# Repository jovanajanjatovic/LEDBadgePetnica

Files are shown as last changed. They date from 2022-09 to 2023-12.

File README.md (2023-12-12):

srp:

# LED bedž sa mogućom kontrolom preko MCU (Mikrokontroler)

## Ovo je opis projekta LED bedž. Isplaniran, projektovan i realizovan u ISPetnica. 
### http://petnica.rs/

```markdown
<-------------------------------------------------------->
    Autori projekta:

        Jovana Janjatović:
            Email: jovana.janjatovic.05@gmail.com
            Github: https://github.com/jovanajanjatovic

        Mihajlo Ninkov:
            Email: mih.nin05@gmail.com
            Github: https://github.com/MihajloNin

        Kosta Jovanović:
            Email: kosta.jovanovic@gmail.com
            Github: https://github.com/KostaJovanovic
<-------------------------------------------------------->
```

## Cilj i opis projekta



Cilj projekta je kompletno dizajniranje PCB ploče sa LED diodama u obliku logoa IS Petnice, gde mikrokontroler omogućava kontrolu nad osvetljenjem pojedinačnih boja.



Izrada prve verzije projekta trajala je od 31.8.2022. do 10.9.2022 na letnjem seminaru elektronike u IS Petnica.
Dizajnirano je za okrugli PCB poluprečnika 3cm, koristeći SMD (surface-mounted device) i TH (through-hole) komponente.



Dizajnirano je sa idejom da se nosi kao bedž, ali to nije ograničenje.



## Hardver

```markdown
Korišćene komponente:
    22 LED diode:
        plave: 7 ()
        zelene: 3 ()
        žute: 5 ()
        crvene: 3 ()
        tamno plave (zamena za ljubičaste): 3;
    5 dioda;
    19 otpornika;
    5 NPN Bipolarnih tranzistora;
    3 držača za 3V Dugmaste baterije;
    1 CONN-SIL2 konektor;
    1 CONN-SIL7 konektor;
```

### Ideje i planovi:

Potrebno je napraviti kućište od klirita (mlečne plastke), na koje će sa unutrašnje strane biti zalepljeni držači za baterije, sa spoljne prekidač, a prednja strana bi koristila isključivo za difuziju svetla sa dioda.

Trenutni plan je da pošaljemo prvu stabilnu verziju ploče na izradu, kako bismo fizički mogli videti prednosti i mana našeg projekta, kako bismo ga optimizovali za širu proizvodnju.

Krajnji cilj projekta je da LED bedževi budu prodavani u petnici, do čega još uvek imamo dug put pred sobom.

### unapređenje:

Plan je da prilagodimo napajanje kako bi baterije činile manji udeo bedža.
Posle prve izrade ploče da ustanovimo prednosti i mane kako bismo imali jasnu sliku stvari koje možda moraju da budu drugačije.

<------>
<------>
<------>

en:

# LED badge optionally controlled with an MCU

## Project description

The goal of the project is the complete design of a PCB board with LEDs in the form of the ISPetnica logo, where the microcontroller enables control over the lighting of individual colors.

The development of the first version of the project lasted from August 31, 2022. until September 10, 2022 at the summer electronics seminar.
It is designed for a round PCB with a radius of 3cm, using SMD (surface-mounted device) and TH (through-hole) components

It's designed with the idea of being worn as a badge, but that's not a limitation.

```markdown

──▒▒▒▒▒▒───▄████▄
─▒─▄▒─▄▒──███▄█▀
─▒▒▒▒▒▒▒─▐████──█─█
─▒▒▒▒▒▒▒──█████▄
─▒─▒─▒─▒───▀████▀

```

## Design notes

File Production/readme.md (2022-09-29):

Ovde će se nalaziti fajlovi koji su relevantni za proizvodnju - BOM, PNP, GERBERI

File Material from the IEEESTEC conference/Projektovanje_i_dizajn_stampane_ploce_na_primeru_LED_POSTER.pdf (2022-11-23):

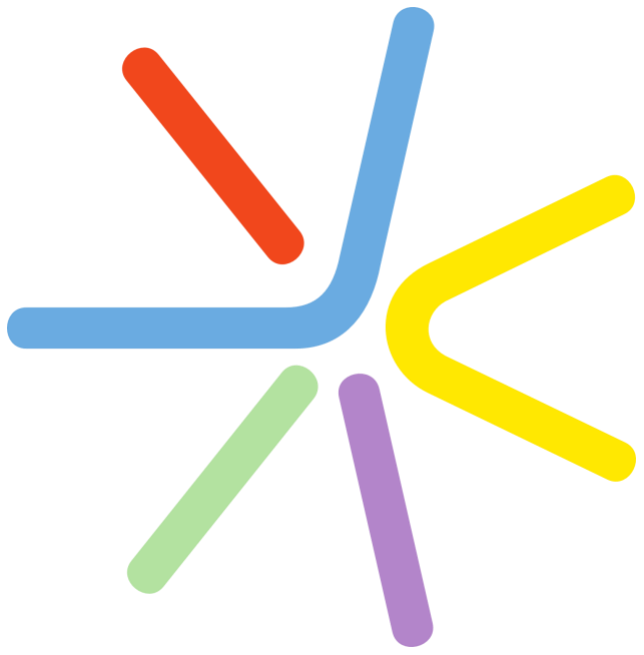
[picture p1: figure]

# Projektovanje i dizajn štampane ploče na primeru LED bedža

## Jovana Janjatović, Kosta Jovanović, Mihajlo Ninkov

- Projekat je rađen u okviru seminara elektronike u Istraživačkoj Stanici Petnica, pa je samim tim projektovana štampana ploča sa motivima logoa IS Petnica.

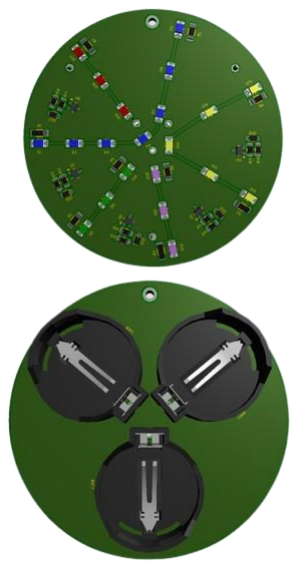
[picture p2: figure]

## Šema električnog kola

- Za ovu šemu je korišćeno:
- 22 LE SMD diode u 5 različitih boja
- SMD diode
- SMD otpornici različitih vrednosti otpornosti
- NPN bipolarnih SMD tranzistora
- Držač za dugmastu bateriju (3V)
- Konektori

## Dizajn štampane ploče

- Početna ideja je da se na jednoj strani nalaze samo LE diode, dok ostale treba da budu smeštene sa zadnje strane, međutim sve komponente na jednoj strani ploče predstavljaju kompaktniju i jeftiniju alternativu.
- Sve SMD komponente će biti lemljene od strane proizvođača ploče, dok će ostatak biti sastavljan ručno.
- Površina ploče je dizajnirana tako da vrši funkciju uzemljenja.

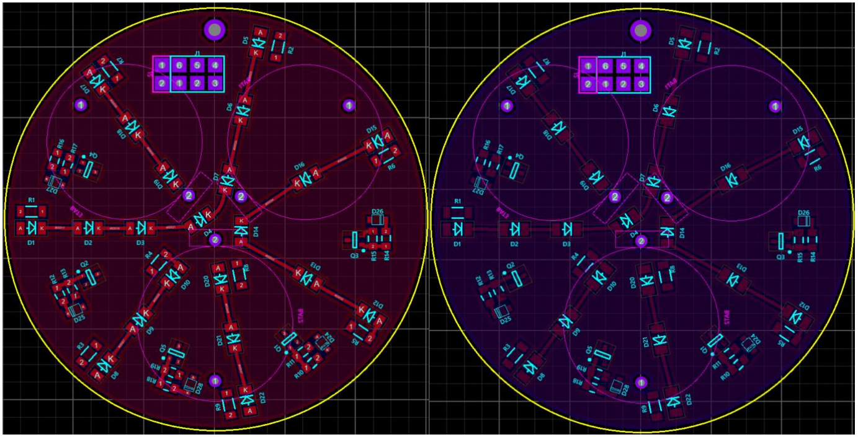
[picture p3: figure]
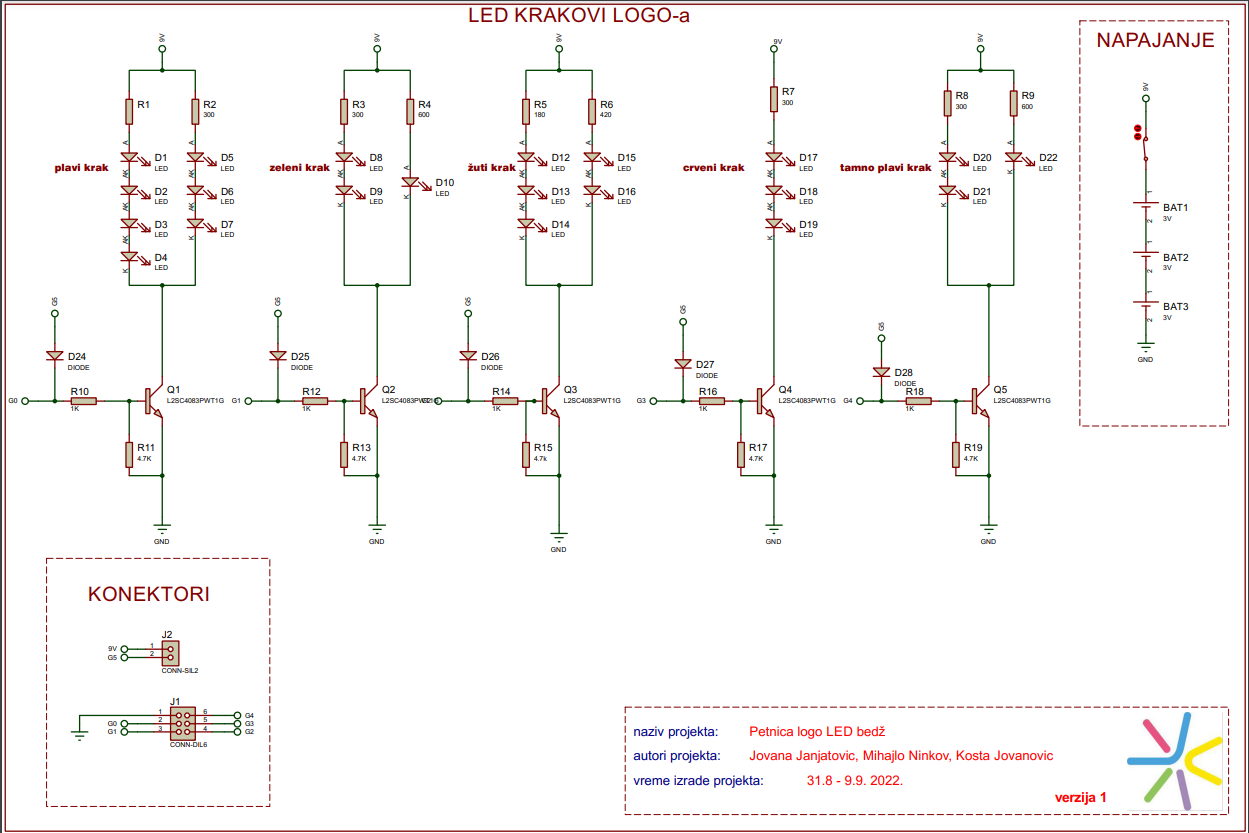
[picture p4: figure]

Jovana Janjatović
Šabačka gimnazija
Šabac
jovana.janjatovic.05@gmail.com

Mihajlo Ninkov
Gimnazija „Jovan Jovanović Zmaj“ Novi Sad
mih.nin05@gmail.com

Kosta Jovanović
V beogradska gimnazija
Beograd
kosta.jovanovic@gmail.com
- Korišćene | su | SMD
komponente | | radi
kompaktnosti sistema.
- Ovaj proces podrazumeva i izradu finalne dokumentacije - Gerber, BOM i P&P fajl

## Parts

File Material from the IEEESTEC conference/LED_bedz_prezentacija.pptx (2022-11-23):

## Projektovanje i dizajn štampane ploče na primeru LED bedža

Jovana Janjatović
Kosta Jovanović
Mihajlo Ninkov

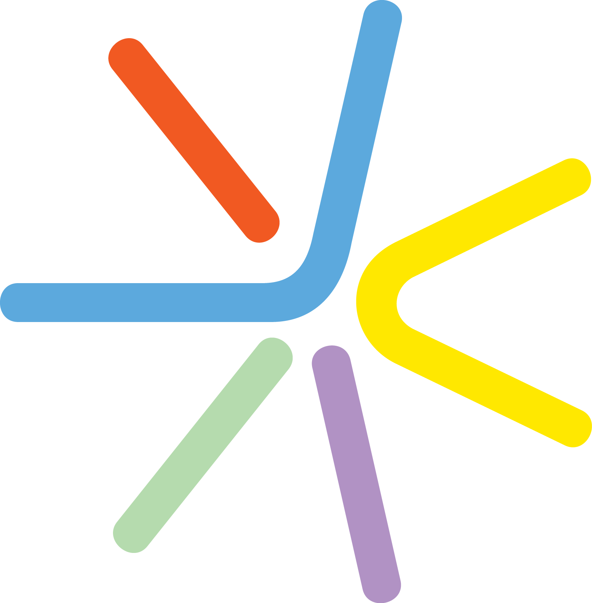
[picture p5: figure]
Seminar Astronomije - ISP -

IEEESTAC konferencija
Novembar 2022.

## IDEJA PROJEKTA

- Željene osobine našeg bedža:
  - Emitovanje svetlosti u bojama logoa IS Petnice
  - Lagana i malih dimenzija
  - Mogućnost kontrole rada diode koristeći Arduino mikrokontroler

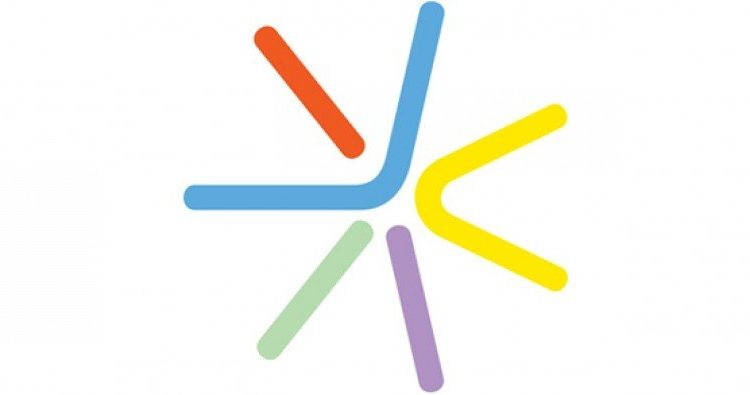
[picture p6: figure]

## OD IDEJE DO BEDŽA

1. Odabir odgovarajućih elektronskih komponenti i računanje nepoznatih vrednosti
  - 22 LED diode u 5 različiith boja;
  - diode;
  - Otpornici različitih otpornosti;
  - NPN bipolarni tranzistori;
  - Držači za 3V dugmaste baterije;
  - Konektori.

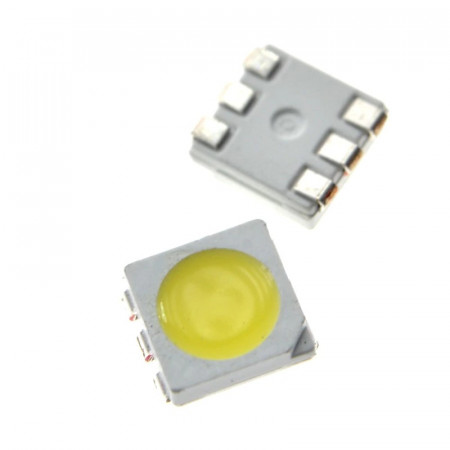
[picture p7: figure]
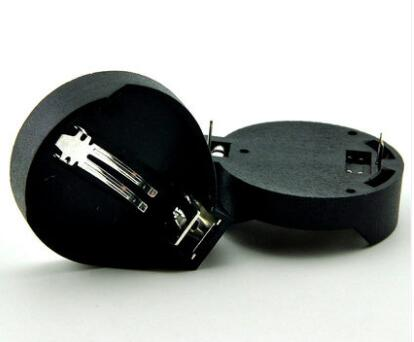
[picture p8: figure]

## OD IDEJE DO BEDŽA

2. Šematski prikaz sistema


## OD IDEJE DO BEDŽA

3. Raspoređivanje i povezivanje komponenti na PCB ploči
PCB (Printed Circuit Board) - pasivna elektronska komponenta koja omogućava ostvarivanje veze između elektronskih komponenti koja su na njoj montirane

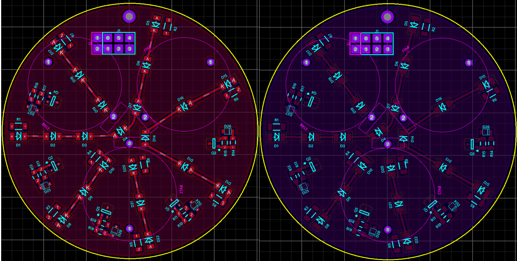
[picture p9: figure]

## OD IDEJE DO BEDŽA

4. Izrada dokumentacije neophodne za industrijsko sastavljanje PCB-a
  - BOM file
  - PnP file
  - Gerber file

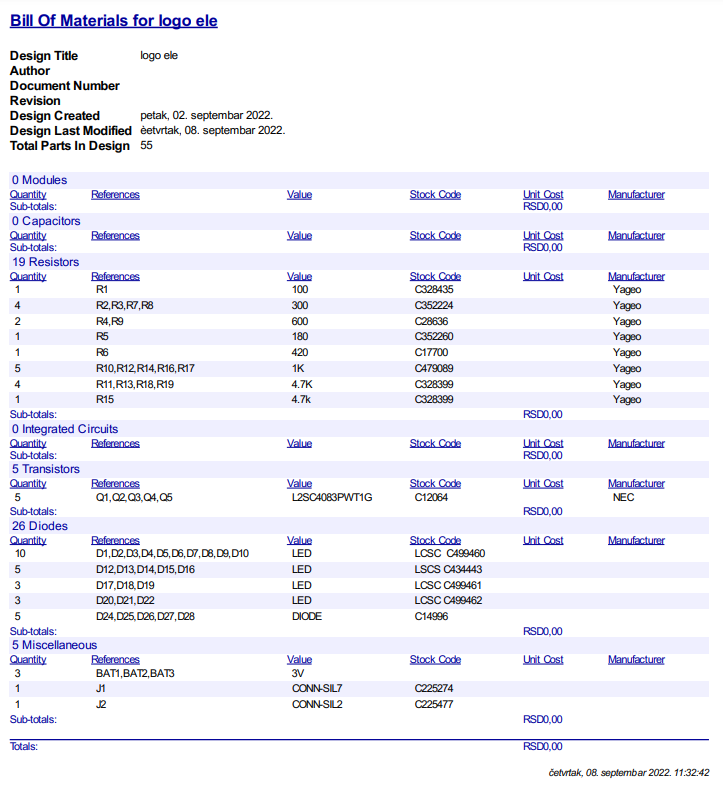
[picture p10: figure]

## PLOČA U PRVOJ ZAVRŠNOJ FAZI

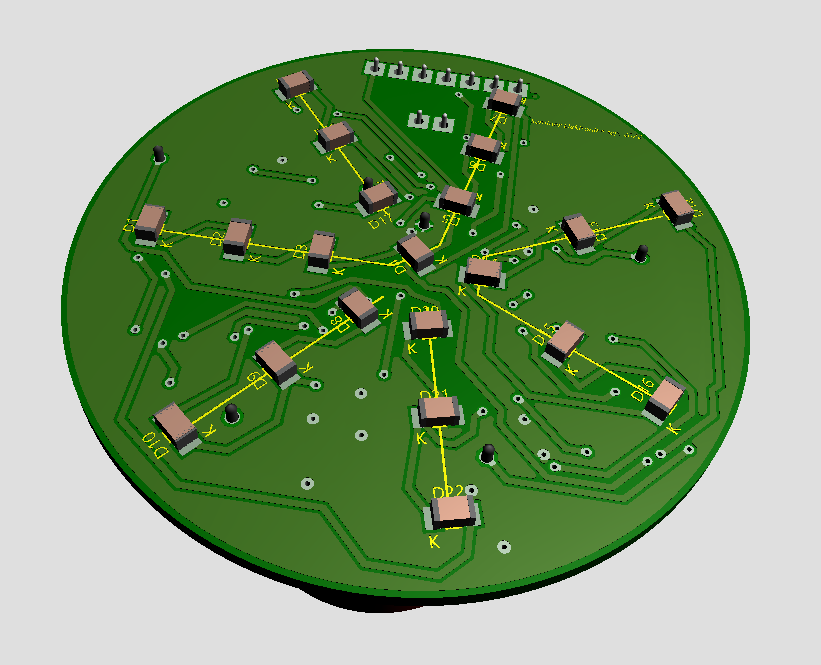
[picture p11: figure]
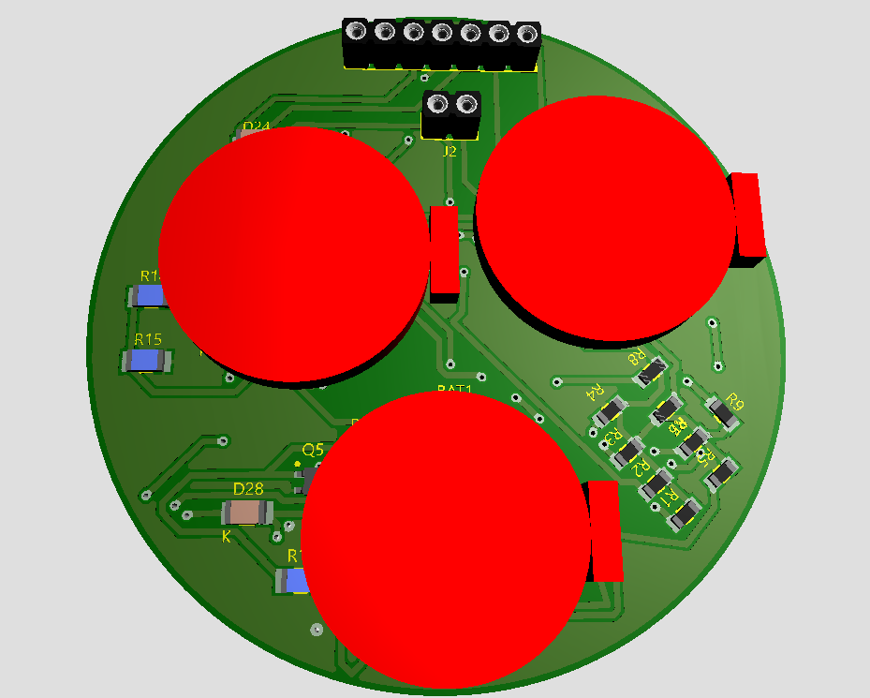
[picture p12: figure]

## Finalni izgled


## „PETNIČKI BEDŽ“ U BUDUĆNOSTI

- Razvijanje projekta:
  - Konstrukcija zaštitnog kućišta
  - Unapređivanje kvaliteta logoa
- Ideje za unapređivanje projekta:
  - Nezavisna kontrola svake diode pojedinačno
  - Optimizacija u komercijalne svrhe
  - Unapredjenje izvora napajanja
  - Dodavanje većeg broja LED dioda

## HVALA NA PAŽNJI!


Kompletan projekat


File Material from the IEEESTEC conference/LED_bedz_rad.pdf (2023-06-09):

# Projektovanje i dizajn štampane ploče na primeru LED bedža

## Jovana Janjatović, Kosta Jovanović, Mihajlo Ninkov

Sadržaj - U ovom radu se opisuje postupak izrade autentične štampane ploče (PCB) koja bi vršila funkciju svetlećeg LED bedža. Uzimajući u obzir da je ovaj rad rađen u Istraživačkoj Stanici Petnica kao seminarski projekat troje polaznika seminara elektronike, motiv ovog LED bedža je logo IS Petnica. U cilju interakcije korisnika sa štampanom pločom (bedžom), uvedena je
mogućnost | kontrolisanja | LE | dioda | pomoću | Arduino
mikrokontrolera. | U nastavku | rada, | detaljno je | opisana
metodologija izrade ovog projekta, kao i korišćene komponente, tehnike i izrada završnih dokumenata.

### I. UVOD

PCB (Printed Circuit Board), odnosno štampana ploča, predstavlja pasivnu elektronsku komponentu koja omogućava ostvarivanje veze među ostalim elektronskim komponentama. Najbitnija podela štampanih ploča je na jednoslojne i višeslojne.
Kod jednoslojnih štampanih ploča, komponente su najčešće naslagane sa jedne, a trake (provodnici) sa druge, dok se između ta dva sloja nalazi sloj izolacije. Međutim, nije nužno da jednoslojna štampana ploča sadrži provodnički element sa obe strane. Kod nekih specijalnih primena, štampana ploča sadrži provodnik samo sa jedne strane, dok se na drugoj nalazi izolatorska ploča. Višeslojne štampane ploče se koriste kod složenih elektronskih kola. Sastoje se od naizmenično raspoređenih slojeva provodnog i izolacionog materijala spojenih zajedno. Provodni slojevi su povezani preko metaliziranih otvora koji se koriste kako za montiranje, tako i za električno povezivanje komponenata.
U ovom radu opisan je postupak dizajniranja štampane ploče koristeći Proteuss 8 Professional program za dizajn štampane ploče i LCSC bazu komponenti [1]. Ovaj projekat rađen je u okviru seminara elektronike u Istraživačkoj Stanici Petnica, pa je samim tim projektovana štampana ploča sa motivima logoa IS Petnica (slika 1). Iscrtavanje šeme i dizajn štampane ploče je rađen u programu Proteus 8 Professional.

Slika 1. Logo IS Petnica.

II. ŠEMA ELEKTRIČNOG KOLA

Prvi korak u izradi projekta je bila električna šema. (Slika 2) [2,3].
Za ovu šemu je korišćeno:
- 22 LE SMD diode u 5 različitih boja [6]
- SMD diode [7]
- SMD otpornici različitih vrednosti otpornosti [5]
- NPN bipolarnih SMD tranzistora [8]
- Držač za dugmastu bateriju (3V)
- Konektori

Radi postizanja najveće moguće kompaktnosti celog sistema, korišćene su tzv. SMD komponente (Surface-Mount Device), koje se leme na površinu štampane ploče i znatno su manjih dimenzija u odnosu na komponente sa izvodima TH (Through Hole).
Prvi problem koji se pojavljuje jeste to što u bazi komponenata kompanije JLCPCB, koja bi trebalo da bude zadužena za izradu ove štampane ploče, ne postoji LE dioda koja emituje ljubičastu svetlost. Rešenje ovog problema jeste da se umesto ljubičaste koristi plava dioda koje emituju svetlost veće talasne dužine od plave koja se već korisiti za dva kraka.
Kako bi se izbeglo nošenje glomaznih baterija od 9 V i više, sa zadnje strane ploče je planirano postavljanje 3 držača dugmaste baterije od 3 V, zato što predstavljaju dosta manju i laganiju alternativu ideji početnog napajanja. Uzimajući u obzir da LE diode različitih boja zahtevaju različit radni napon, a poštujući i I Kirhofov zakon, bilo je potrebno razdeliti LE diode i ostale elektronske komponente u više grana kako bi se ideja sa postavljanjem baterije od 9 V koja napaja ceo sistem pokazala izvodljivom.
Raspodelom neophodnih komponenti u odgovarajući redosled na šematskom prikazu, pojavila se potreba za unapređenjem sistema, u vidu mogućnosti za kontrolu
svake | boje | logoa | nezavisno | koristeći | Arduino
mikrokontroler. Dodavanjem NPN bipolarnih tranzistora na svaku granu električne šeme i prespojnika koji bi vršili funkciju provodnika u slučajevima kada mikrokontroler
J. Janjatović je učenica treće godine Šabačke gimnazije,
Masarikova | 13, | 15000 | Šabac, | Srbija. | E-mail:
jovana.janjatovic.05@gmail.com
K. Jovanović je učenik četvrte godine V beogradske gimnazije, Ilije Garašanina 24, 11000 Beograd, Srbija. E-mail: kosta.jovanovic@gmail.com
M. Ninkov je učenik treće godine gimnazije „Jovan Jovanović Zmaj“, Zlatne grede 4, 21000 Novi Sad, Srbija. E-mail: mih.nin05@gmail.com nije priključen, korisnik je dobio mogućnost da po sopstvenoj želji isprojektuje šablon po kom će LE diode funkcionisati.


Slika 2. Šema električnog kola.

III. DIZAJN ŠTAMPANE PLOČE

Nakon | kompletirane | šeme | sa | svim | željenim
komponentama, neophodno je sve te komponente rasporediti u određeni raspored na štampanoj ploči. Kako bi LE diode raspodelili najpreciznije moguće, Petnički logo je prebačen u monohromatsku sliku, a zatim je sačuvan kao .bitmap dokument, iz razlog zašto je to jedini format fotografije koji Proteus dozvoljava kao uvoz. Kada su sve LE diode bile na svojim mestima, usledila je raspodela ostalih komponenti na štampanu ploču, tako da ploča zadrži kompaktan i funkcionalan izgled, odnosno da svaka komponenta ima mogućnost da se poveže u kolo, tako da ne remeti rad kako LE dioda tako i ostalih komponenti. Ideja je da se na jednoj strani nalaze samo LE diode, dok ostale treba da budu smeštene sa zadnje strane i da budu povezane viama sa prednjom stranom, da ne bi remetile rad LE dioda.
Daljim istraživanjem, uviđeno je da je znatno jeftinije i brže ukoliko sve komponente stoje na jednoj strani ploče. Iz tog razloga, ploča je dizajnirana tako da ispunjava prethodno navedene potrebe, ali i da sadrži komponente isključivo na jednoj strani.
Povezivajući komponente putevima (trace), pojavio se naredni problem, tačnije, nije moguće povezati dve komponente tako da put između njih na bilo kom svom delu skreće pod pravim uglom zato što u tom slučaju ima ulogu odašiljača signala.
Budući da će sve TH komponente biti lemljene u Srbiji, nije postojao 3D model i otisak (eng. footprint) na ploči u bazi komponenti programa u kom je projekat rađen, osim konektora, pa je bilo neophodno projektovati 3D model (u programu za 3D modelovanje – Fusion 360) i otisak na ploči (u Proteus 8 Professional) [1,9].

Jedna od stvari koje su znatno olakšale postpuak izrade jeste postavljanje površine obe strane ploče tako da vrši ulogu uzemljenja.
Finalni izgled štampane ploče prikazan je na slikama 3 i 4.


Slika 3. Prednja strana štampane ploče.


Slika 4. Zadnja strana štampane ploče.

IV. DOKUMENTACIJA

Po završetku procesa dizajna štampane ploče, neophodne je precizirati postupak izrade kompaniji kojoj se šalje ploča na izradu. U ovom slučaju, štampana ploča će biti izrađena od strane kompanije JLCPCB. Kako bi se precizno definisao postupak izrade neophodno je sastaviti tri ključna dokumenta - BOM, P&P i Gerber fajl.
Gerber
Izrada | proizvodne | dokumentacije | podrazumeva
generisanje i proveru Gerber fajlova. Ovi fajlovi sadrže podatke, kao što su koordinate za bušenje rupa sa definisanim prečnicima, referentne tačke... GERBER je standardni format za uređaje u proizvodnji štampanih ploča.

BOM
BOM fajl (Bill of Materials) predstavlja spisak svih komponenti potrebnih za proizvodnju štampane ploče. Postoje različiti tipovi BOM fajlova, ali svaki od njih mora sadržati:
- šifru proizvoda - karakteristična je za firmu koja je dizajnirala štampanu ploču
- karakteristike komponenti: na primer: otpornost, kapacitivnost...
- oznaku: na samoj štampanoj ploči, svakoj komponenti dato je ime koje je sastavljeno od slova (koje je uglavnom karakteristično za vrstu komponente, na primer: otpornik - R, kondenzator - C...) i broja (koji označava koja je po redu to komponenta određene vrste) Izuzetno je važno redovno ažurirati BOM file tokom dizajniranja jer je on ključni aspekt i dizajna štampane ploče i njene montaže. Kad god se doda nova komponenta tokom procesa dizajniranja, treba se uveriti da je BOM ažuriran sa ispravnom šifrom delova, opisom i količine komponenata.

PnP
P&P fajl (Pick & Place) je lista komponenti i njihovih koordinata. Ova vrsta fajla je neophodna za automatsko montiranje, jer daje instrukcije mašini, kao što su pozicija i orijentacija željene komponente. Svaki PnP file mora sadržati:
- oznaku: o kojoj komponenti je reč (npr: C21, L15...).
- preporučene jedinice: uglavnom je po metarskom sistemu to milimetar (mm).
- Layer - Top / Bottom, odnosno na kojoj strani ploče se nalazi komponenta: gornjoj/donjoj.
- Rotaciju: rotaciju date komponente izražene u stepenima. Vrednost je pozitivna za rotaciju u smeru kretanja kazaljke na satu.


Slika 5. Finalni izgled štampane ploče.

V. ZAKLJUČAK

Nakon prolaska kroz kompletan proces izrade štampane ploče, zaključak je da je uz malo predznanje itekako moguće dizajnirati štampanu ploču sa proizvoljnom namenom poput ukrasa, funkcionalnog upravljača za mašine itd...
Ovaj projekat ima dosta mogućnosti za dalji napredak. Planovi za buduće modifikacije ploče su:
-Postavljanje svih komonenti na jednu stranu kako bi smanjili cenu izrade štampane ploče
-Dodavanje novih LE dioda radi "gušće" slike logoa -Postavljanje štampane ploče u plastično kućište, koje će pored zaštitne svrhe, sadržati mlečnu plastiku ili klirit koji će da raširi svetlost radi jasnije slike
-Zamena 3 baterije od 3 V za jednu bateriju od 3 V koja se može pojačati DC-DC konverterom

Sve detaljnije informacije se nalaze na GitHubu: https://github.com/jovanajanjatovic/LEDBadgePetnica .git (https://github.com/jovanajanjatovic/LEDBadgePetnica.git)
LITERATURA

[1] Proteus | 8 | Professional. | Dostupno | na:
https://www.labcenter.com/.
[2] B. Antić “Uvod u projektovanje štampanih ploča” Mart 2009.
[3] D. Danković “Projektovanje štampanih ploča” Katedra za mikroelektroniku, Elektronski fakultet, Univerzitet u Nišu, 2017.
[5] Tehničke informacije korišćenih otpornika:
- https://datasheet.lcsc.com/lcsc/2206010130_UNI-ROYAL-Uniroyal-Elec-0603WAF1001T5E_C21190.pdf (https://datasheet.lcsc.com/lcsc/2206010130_UNI-ROYAL-Uniroyal-Elec-0603WAF1001T5E_C21190.pdf)
- https://datasheet.lcsc.com/lcsc/1912111437_Resistor-Today-ETCR0603F180RK9_C365391.pdf (https://datasheet.lcsc.com/lcsc/1912111437_Resistor-Today-ETCR0603F180RK9_C365391.pdf)
- https://datasheet.lcsc.com/lcsc/2004211033_Resistor-Today-PTFR0805B1K00P9_C479089.pdf (https://datasheet.lcsc.com/lcsc/2004211033_Resistor-Today-PTFR0805B1K00P9_C479089.pdf)
[6] Tehničke informacije koričćenih LE dioda:
- https://datasheet.lcsc.com/lcsc/2009091206_HONGLIT RONIC-Hongli-Zhihui--HONGLITRONIC--HL-PC-3216U97GC-L_C499460.pdf (https://datasheet.lcsc.com/lcsc/2009091206_HONGLITRONIC-Hongli-Zhihui--HONGLITRONIC--HL-PC-3216U97GC-L_C499460.pdf)
- https://datasheet.lcsc.com/lcsc/2008271733_Yongyu-Photoelectric-SZYY1206Y_C434443.pdf (https://datasheet.lcsc.com/lcsc/2008271733_Yongyu-Photoelectric-SZYY1206Y_C434443.pdf)
- https://datasheet.lcsc.com/lcsc/2009091206_HONGLIT RONIC-Hongli-Zhihui--HONGLITRONIC--HL-PC-3216S52FC-L_C499461.pdf (https://datasheet.lcsc.com/lcsc/2009091206_HONGLITRONIC-Hongli-Zhihui--HONGLITRONIC--HL-PC-3216S52FC-L_C499461.pdf)
- https://datasheet.lcsc.com/lcsc/2009091206_HONGLIT RONIC-Hongli-Zhihui--HONGLITRONIC--HL-PC-3216H392BC-L_C499462.pdf (https://datasheet.lcsc.com/lcsc/2009091206_HONGLITRONIC-Hongli-Zhihui--HONGLITRONIC--HL-PC-3216H392BC-L_C499462.pdf)
[7] Tehničke informacije korišćenih dioda:
- https://datasheet.lcsc.com/lcsc/1810101110_Jiangsu-Changjing-Electronics-Technology-Co---Ltd--1N4148WS_C2128.pdf (https://datasheet.lcsc.com/lcsc/1810101110_Jiangsu-Changjing-Electronics-Technology-Co---Ltd--1N4148WS_C2128.pdf)

[8] Tehniče informacije korišćenih kondenzatora:
- https://datasheet.lcsc.com/lcsc/1810051107_LRC-L2SC4083PWT1G_C12064.pdf (https://datasheet.lcsc.com/lcsc/1810051107_LRC-L2SC4083PWT1G_C12064.pdf)
[9] | Autodesk | Fusion | 360. | Dostupno | na:
https://www.autodesk.com/products/fusion-360/personal

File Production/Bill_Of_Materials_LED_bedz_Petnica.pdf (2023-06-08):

## Bill Of Materials for LED bedž Petnica

Design Title | LED bedž Petnica
Author | Jovana Janjatović, Mihajlo Ninkov, Kosta Jovanović
Document Number | 1
Revision | Stevan Golubović
Design Created | Wednesday, 7 June 2023
Design Last Modified Wednesday, 7 June 2023

### Total Parts In Design 55

19 Resistors
Quantity | References | PCB Package | Value | Stock Code
1 | R1 | 1206_RES | 100 | C21190
4 | R2-R3,R7-R8 | 1206_RES | 300 | C23025
2 | R4,R9 | 1206_RES | 600 | C28636
1 | R5 | 1206_RES | 180 | C2934148
1 | R6 | 1206_RES | 420 | C17700
5 | R10,R12,R14,R16,R18 | 0805_RES | 1K | C479089
4 | R11,R13,R17,R19 | 0805_RES | 4.7K | C23162
1 | R15 | 0805_RES | 4.7k | C23162
Sub-totals:
5 Transistors
Quantity | References | PCB Package | Value | Stock Code
5 | Q1-Q5 | SOT65P210X110-3 | L2SC4083PWT1G | C12064
Sub-totals:
26 Diodes
Quantity | References | PCB Package | Value | Stock Code
7 | D1-D7 | LED_1206_PLAVA | LED | C84266 (https://www.lcsc.com/product-detail/Light-Emitting-Diodes-LED_Foshan-NationStar-Optoelectronics-NCD0603B1_C84266.html)
3 | D8-D10 | LED_1206_ZELENA | LED | C84266 (https://www.lcsc.com/product-detail/Light-Emitting-Diodes-LED_Foshan-NationStar-Optoelectronics-NCD0603B1_C84266.html)
5 | D12-D16 | LED_1206_ZUTAA | LED | C434443
3 | D17-D19 | LED_1206_CRVENA | LED | C499461
3 | D20-D22 | LED_1206_LJUBICASTA | LED | C499462
5 | D24-D28 | SOD-323 | DIODE | C2128
Sub-totals:
5 Miscellaneous
Quantity | References | PCB Package | Value | Stock Code
3 | BAT1-BAT3 | FINAL_SOCKET | 3V
1 | J1 | CONN-DIL6 | CONN-DIL6 | C225274
1 | J2 | CONN-SIL2 | CONN-SIL2 | C213465
Sub-totals:

Totals:

| | | | Thursday, 8 June 2023 10:03:13

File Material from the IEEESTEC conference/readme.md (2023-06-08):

Ovde se nalaze: 
  - PDF file rada koji je poslat na IEEESTEC konferenciju
  - prezentacija koja je prezentovana na IEEESTEC konferenciji

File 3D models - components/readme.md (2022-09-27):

STEP fajlovi komponenata koje smo uvozili

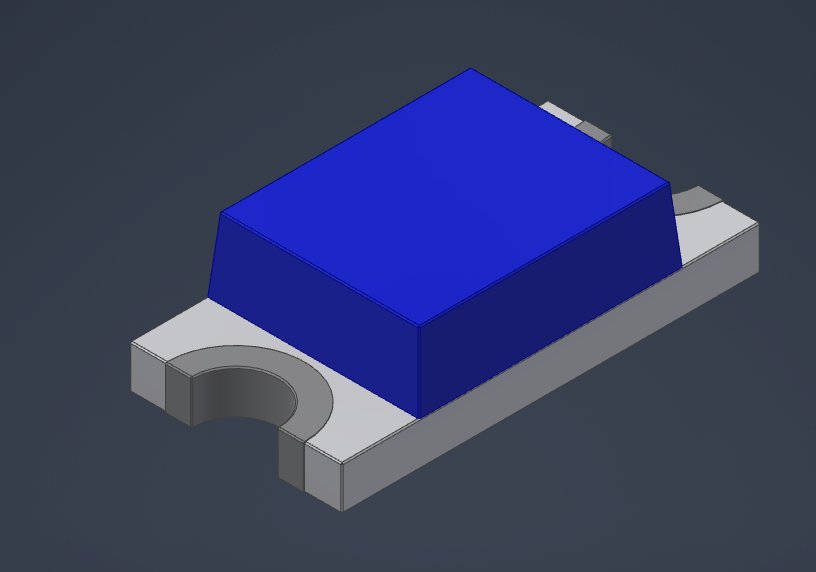
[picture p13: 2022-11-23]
3D models - components/LEDBlue.jpg

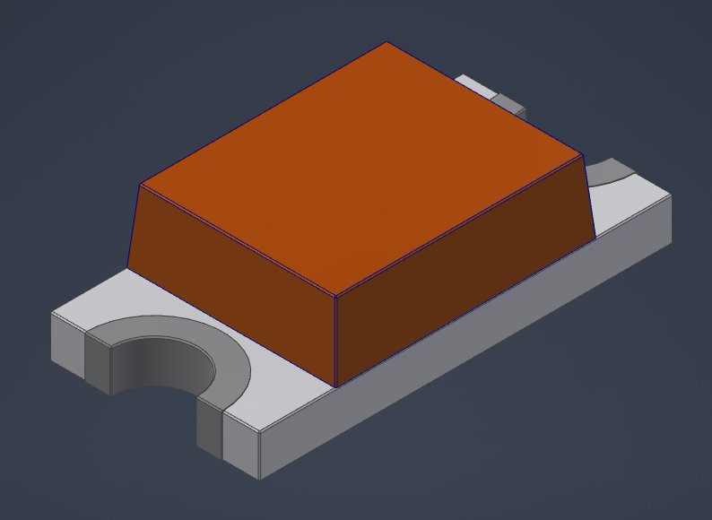
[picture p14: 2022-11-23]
3D models - components/LEDOrange.jpg

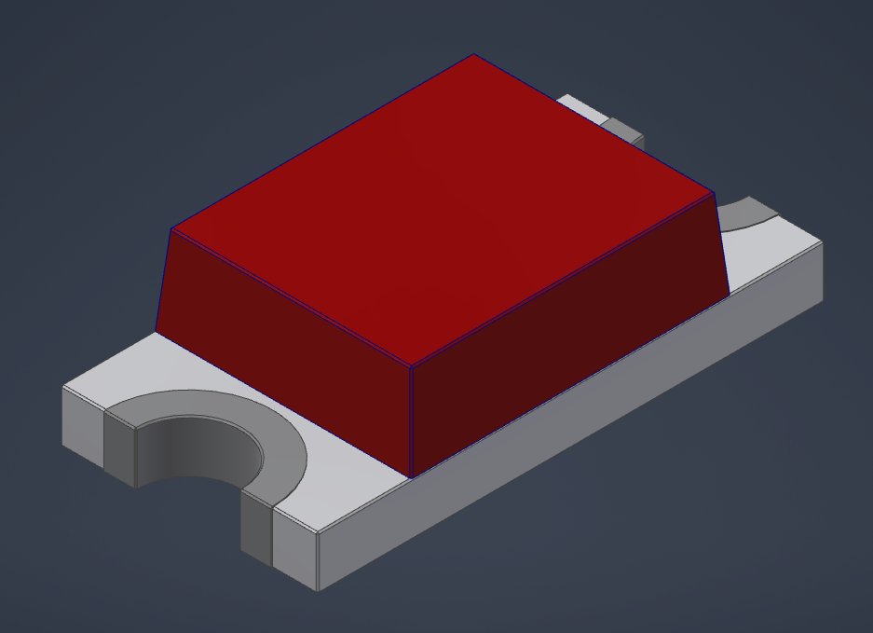
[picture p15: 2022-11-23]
3D models - components/LEDRed.jpg

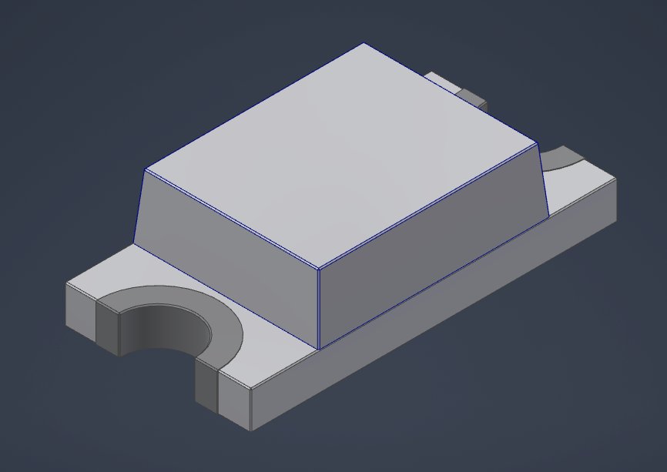
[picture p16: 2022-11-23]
3D models - components/LEDWhite.jpg

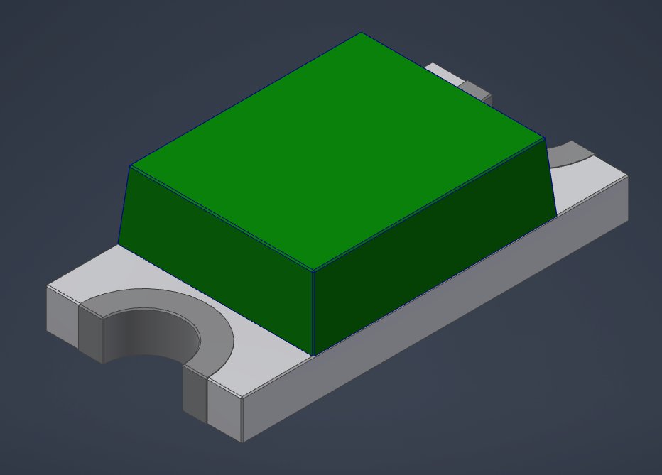
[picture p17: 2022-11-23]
3D models - components/LEDGreen.jpg

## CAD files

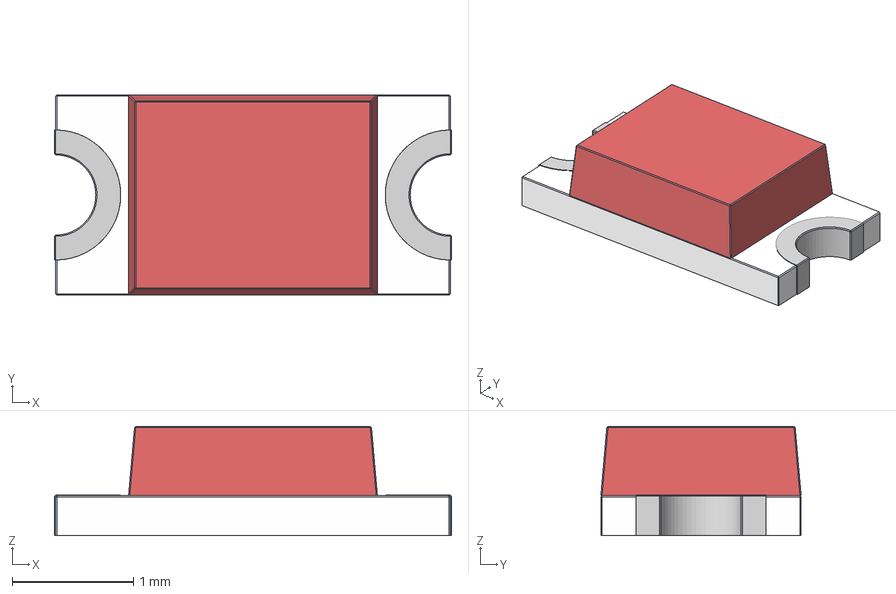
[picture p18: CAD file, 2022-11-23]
3D models - components/LED_1206_Red.stp
3.27 x 1.65 x 0.9 mm

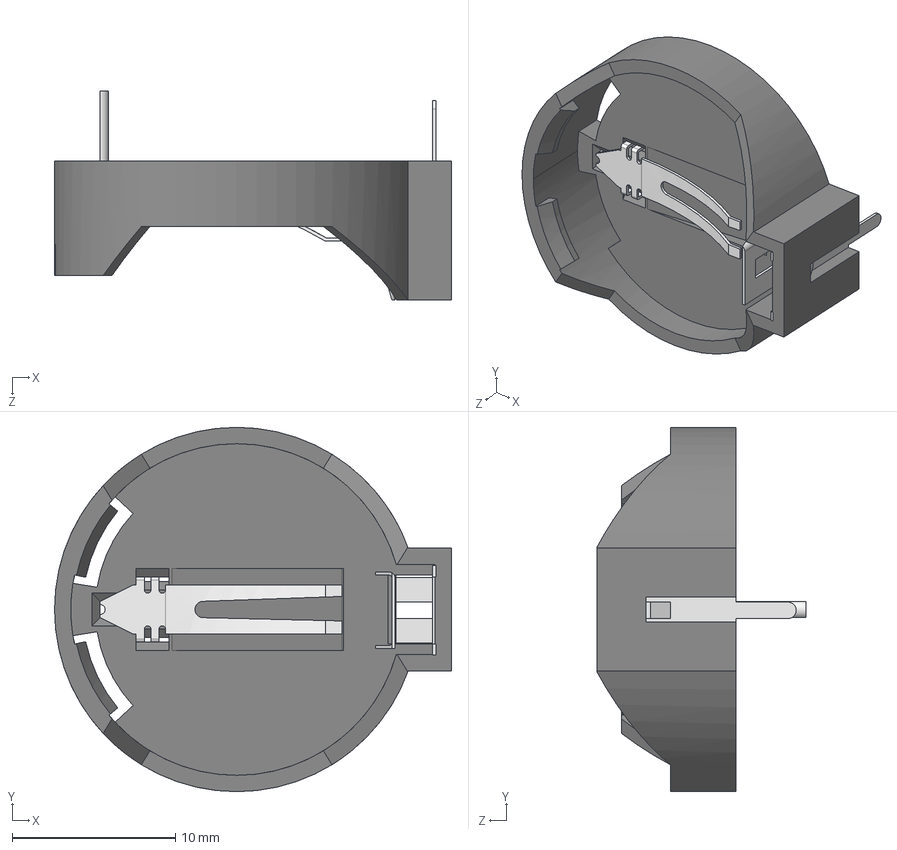
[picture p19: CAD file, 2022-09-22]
BH-642.STEP
24.3 x 22.3 x 12.8 mm
BH-642_Plastic
BH-642_Metal_minus
BH-642_Metal_plus

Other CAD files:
3D models - components/LED_1206_Blue.stp
3D models - components/LED_1206_Green.stp
3D models - components/LED_1206_Orange.stp
3D models - components/LED_1206_White.stp
3D models - components/BH-642.STEP

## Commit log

2022-09-08 pipi und kaki in pipi kaka land
2022-09-08 pipi und kaki in pipi kaka land
    updated design
2022-09-08 BOM, PNP i gerber file dodati
2022-09-10 obrisao bill of materials - bio kopija
2022-09-22 Add files via upload
    Promenjen STEP model soketa za bateriju
    [BH-642.STEP]
2022-09-29 Rename BH-642.STEP to 3D models - components/BH-642.STEP
    [BH-642.STEP]
2022-11-23 Add files via upload
    STEP modeli led dioda
    [LED_1206_Blue.stp, LED_1206_Green.stp, LED_1206_Orange.stp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]
2022-11-23 LED bedž.pptx
    finalna verzija prezentacije
2023-06-08 GERBER
    gerber file
2023-06-08 BOM
    bill of materials
2023-06-09 SOCKET za baterije
2023-06-13 Create Material from the conference
